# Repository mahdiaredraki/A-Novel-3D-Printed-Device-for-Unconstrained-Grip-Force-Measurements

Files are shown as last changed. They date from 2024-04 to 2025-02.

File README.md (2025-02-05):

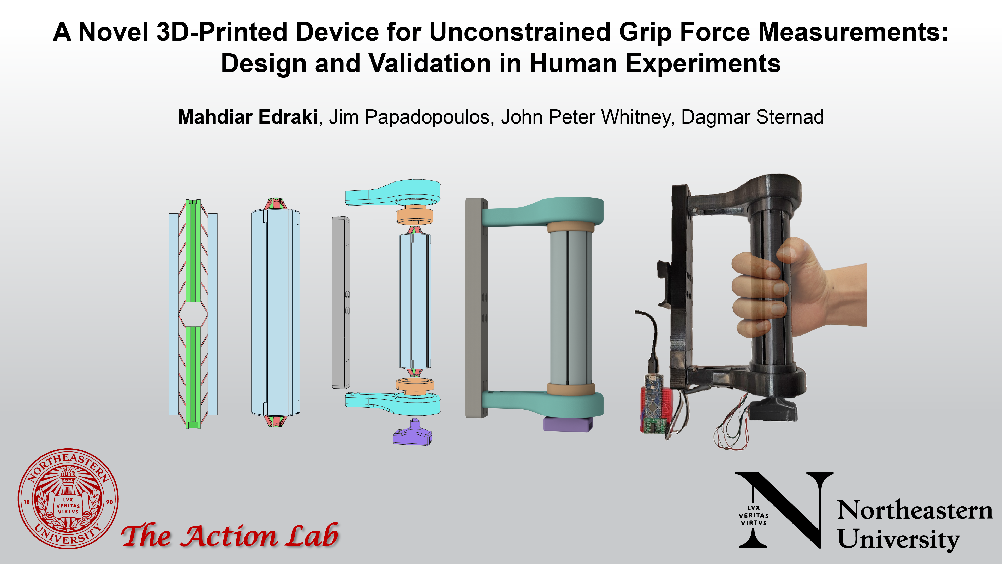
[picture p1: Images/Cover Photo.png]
Cover Photo


This repository contains the source code for the paper "A Novel 3D-Printed Device for Unconstrained Grip Force Measurements: Design and Application in a Human Experiment". This paper has been submitted to IEEE Transactions on Haptics.

## Setup Tutorial
[Click here](https://youtu.be/9uq_tFdBbcg?si=LtT3Q0BiFbUa_C0i) to view a step-by-step tutorial covering how to assemble and calibrate the device.

## Software
### Calibration and Programming of Arduino
The code to calibrate and program the arduino are provided in the [Grip Sensor Code/Arduino](https://github.com/mahdiaredraki/A-Novel-3D-Printed-Device-for-Unconstrained-Grip-Force-Measurements/tree/main/Grip%20Sensor%20Code/Arduino) folder. 

A README file is provided in the folder, explaining the steps to calibrate and program the device.

### Data Collection through MATLAB and C++
The code to record device data using MATLAB and C++ are provided in the [Grip Sensor Code/MATLAB](https://github.com/mahdiaredraki/A-Novel-3D-Printed-Device-for-Unconstrained-Grip-Force-Measurements/tree/main/Grip%20Sensor%20Code/MATLAB) and [Grip Sensor Code/C++](https://github.com/mahdiaredraki/A-Novel-3D-Printed-Device-for-Unconstrained-Grip-Force-Measurements/tree/main/Grip%20Sensor%20Code/C%2B%2B) folders, respectively.

## Hardware
* [Arduino Nano](https://a.co/d/btdwUGS)
* [HX711 Amplifier](https://a.co/d/b6gcvBy)
* [M3 Threaded Rod](https://a.co/d/1BYGkEt)
* [Jumper Wires](https://a.co/d/3KskUcE)
* [M3 Nuts](https://a.co/d/6aupH7b)
* [50kg Load Cell](https://www.aliexpress.us/item/3256803506004709.html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)
* [PLA Filament for 3D Printed Parts](https://a.co/d/9uJcKfV) 

## Assembly and Calibration Tools
* Soldering Iron
* Pliers x2
* Kitchen Scale or any calibrated Load Cell
* Weights

## Wiring Diagram
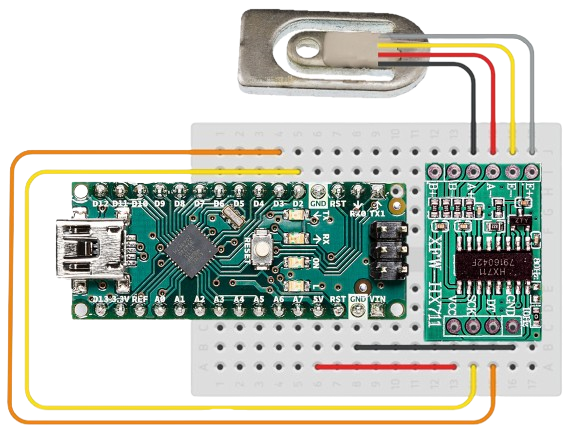
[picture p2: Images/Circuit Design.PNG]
Circuit Design


## 3D-Printed Parts
All CAD files developed in this project are open-sourced and can be found in the [CAD Files](https://github.com/mahdiaredraki/A-Novel-3D-Printed-Device-for-Unconstrained-Grip-Force-Measurements/tree/main/CAD%20Files) folder. All parts have been provided with .SLDPRT, .STL, and .STEP formats.

## Experiment Data
All the data collected and analyzed in this work are made available in the [Experiment Data](https://github.com/mahdiaredraki/A-Novel-3D-Printed-Device-for-Unconstrained-Grip-Force-Measurements/tree/main/Experiment%20Data) folder. The raw and cleaned up data of all seven participants can be found in the [Experiment Data/Participant Datasets](https://github.com/mahdiaredraki/A-Novel-3D-Printed-Device-for-Unconstrained-Grip-Force-Measurements/tree/main/Experiment%20Data/Participant%20Datasets) folder. The data used in the Analysis of Variance (ANOVA) in the study are also provided separately in the [Experiment Data/ANOVA Datasets](https://github.com/mahdiaredraki/A-Novel-3D-Printed-Device-for-Unconstrained-Grip-Force-Measurements/tree/main/Experiment%20Data/ANOVA%20Datasets) folder. 

## Contact Me
If you have any questions or have trouble setting up the device, feel free to reach out to Mahdi Edraki (edraki.m@northeastern.edu).

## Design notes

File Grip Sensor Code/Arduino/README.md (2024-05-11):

## Calibration
1. Open the Calibrate.ino code in Arduino IDE.
2. Upload the program onto the Arduino.
3. Open the Serial Monitor by clicking Tools -> Serial Monitor.
4. Apply a known load to the device.
5. Adjust the device output in the Serial Monitor by entering + or – until the reading matches the applied load.
6. Apply other loads and adjust the reading until a suitable calibration factor is obtained.
7. Note the calibration factor to be used in the Programming step below.

## Programming
1. Open the Program.ino code in Arduino IDE.
2. Modify the value for the calibration_factor variable to the value found in step 7 above.
3. Upload the program onto the Arduino.

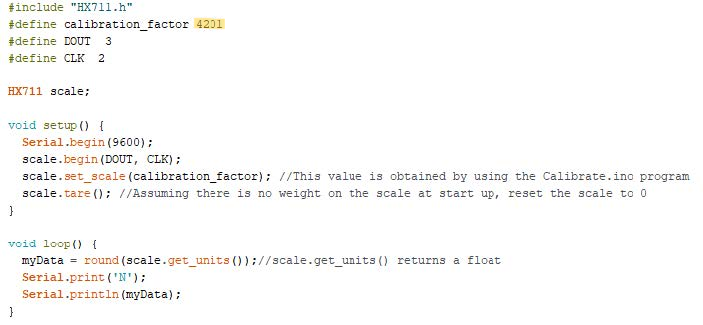
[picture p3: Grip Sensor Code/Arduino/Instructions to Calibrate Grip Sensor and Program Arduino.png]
Calibrate and Program


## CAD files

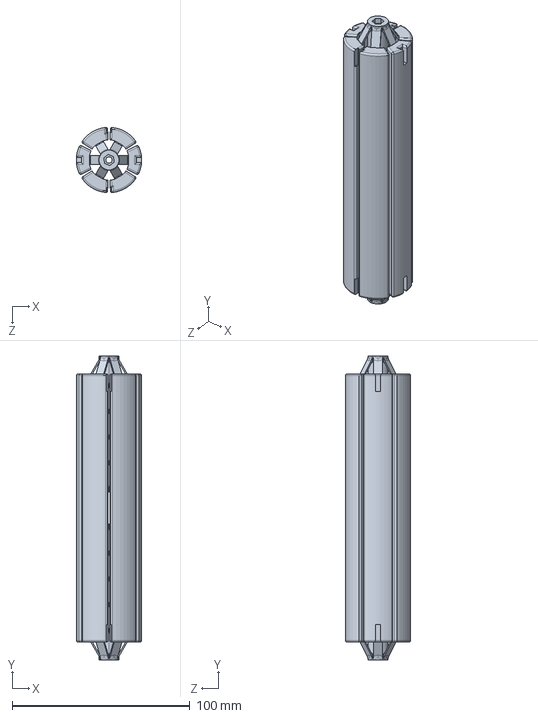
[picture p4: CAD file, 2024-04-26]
CAD Files/Grip Sensor Main Body.STEP
36.8 x 171.0 x 36.6 mm

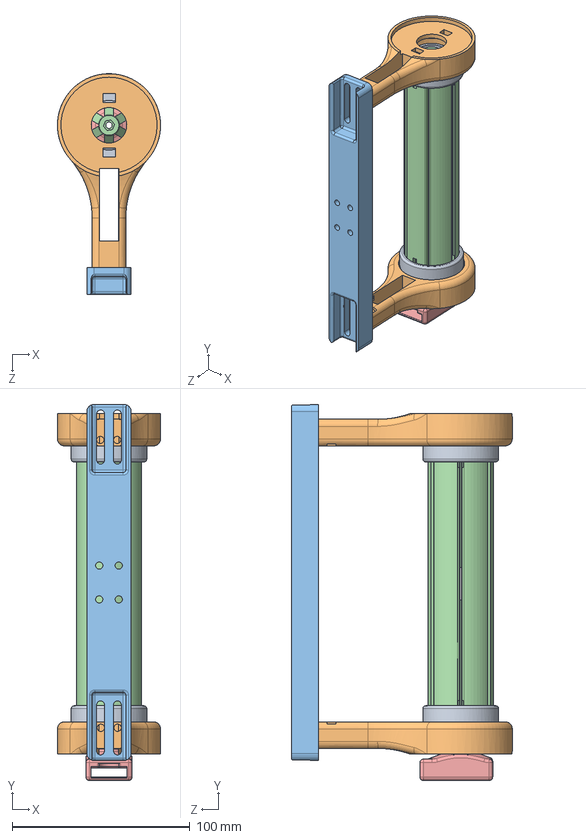
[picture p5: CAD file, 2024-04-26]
CAD Files/Complete Assembly.SLDASM
58.0 x 211.3 x 124.0 mm
Bearing Mount x 2
Handle Mount x 2
Handle Vertical Arm
Grip Sensor Main Body
Load Cell Mount

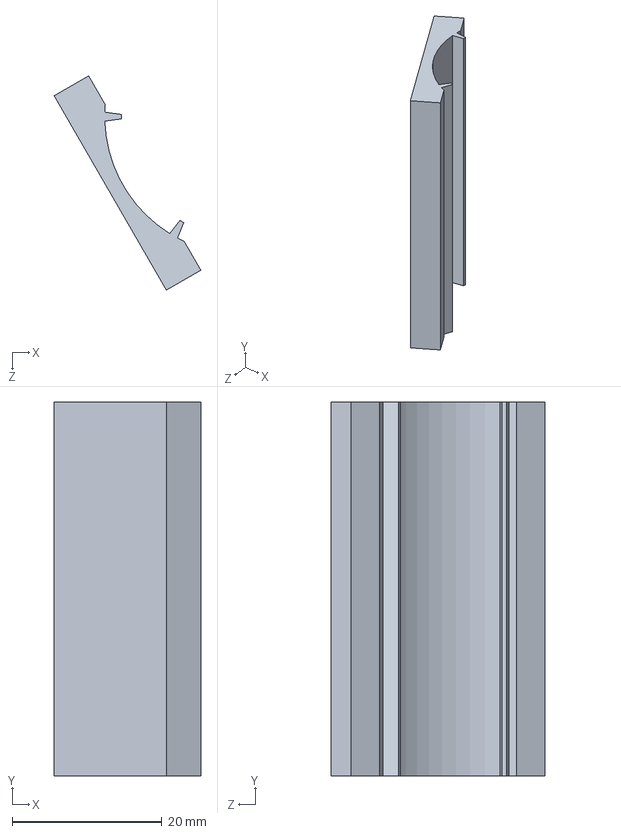
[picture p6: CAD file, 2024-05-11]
CAD Files/Load Application Plate.STEP
19.6 x 50.0 x 28.6 mm

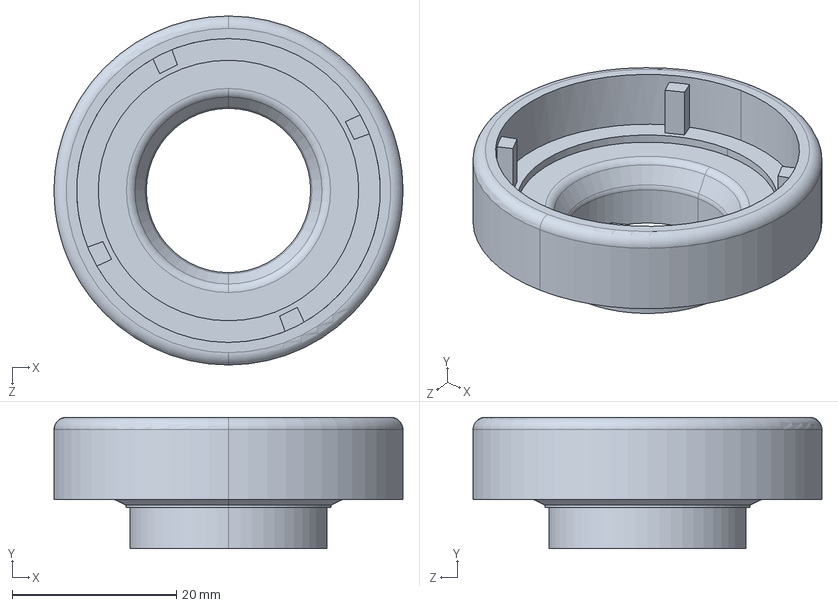
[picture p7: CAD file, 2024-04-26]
CAD Files/Bearing Mount.STEP
42.5 x 16.0 x 42.5 mm

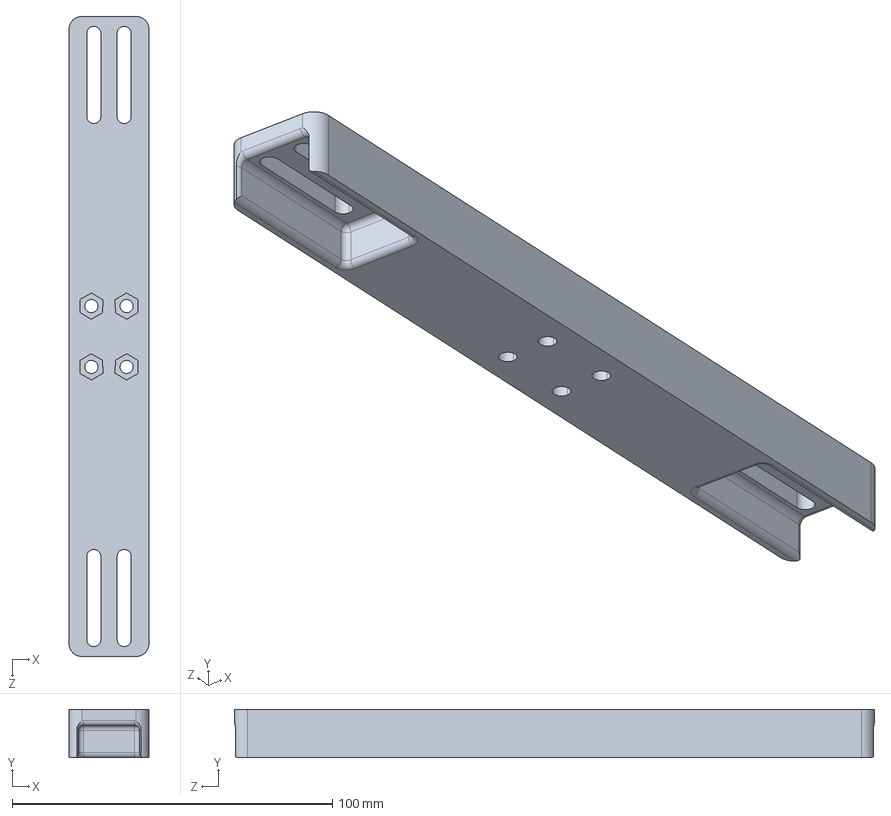
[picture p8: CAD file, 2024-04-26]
CAD Files/Handle Vertical Arm.STEP
25.0 x 15.0 x 200.0 mm

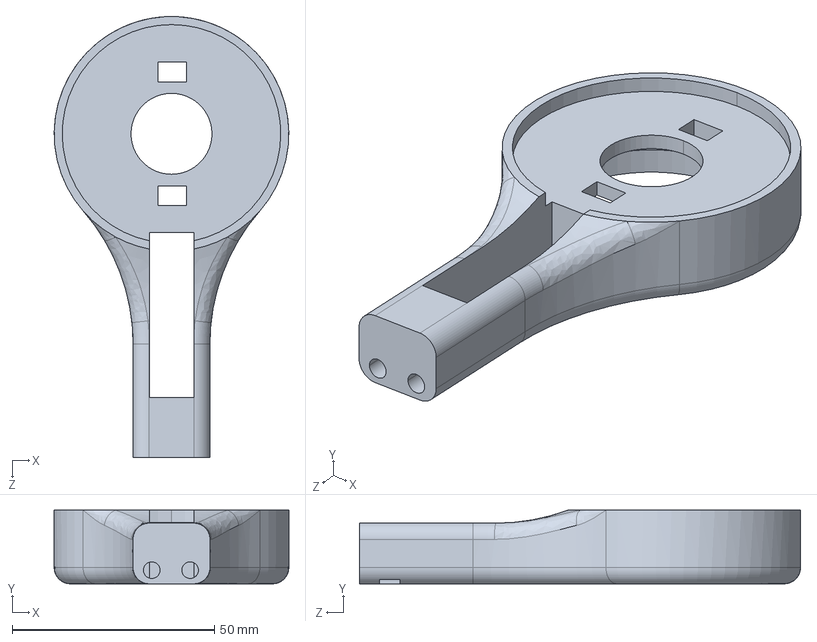
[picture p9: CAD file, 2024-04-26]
CAD Files/Handle Mount.STEP
58.0 x 18.2 x 109.0 mm

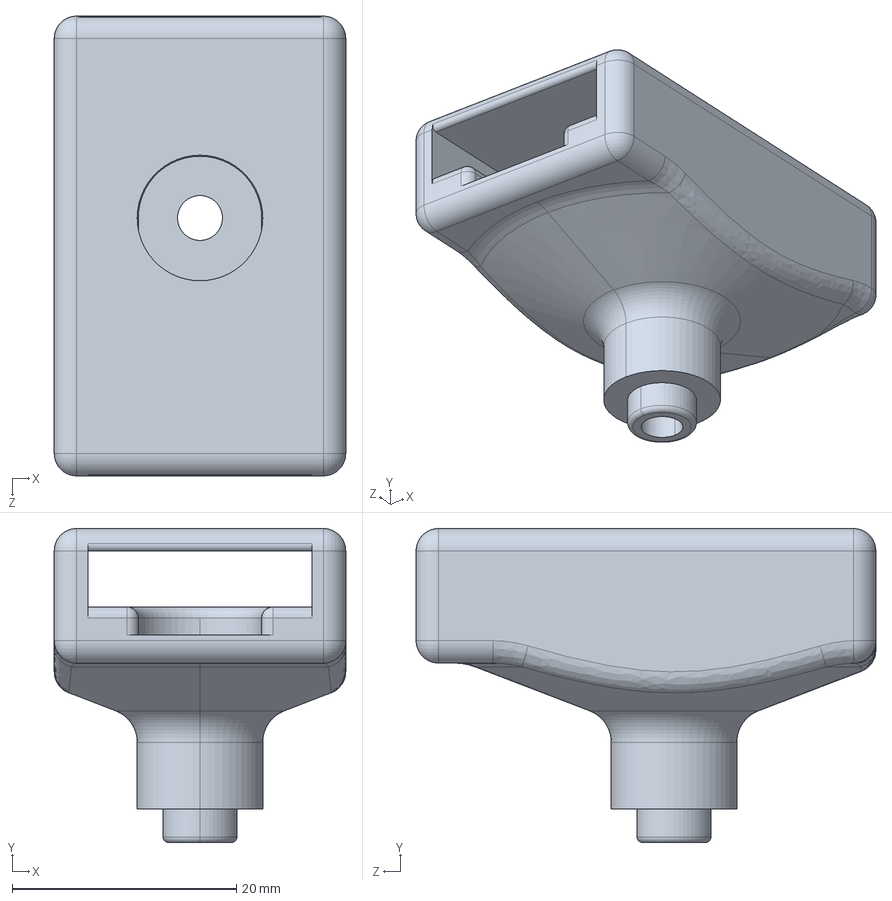
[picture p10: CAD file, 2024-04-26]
CAD Files/Load Cell Mount.STEP
26.0 x 28.0 x 41.0 mm

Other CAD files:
CAD Files/Bearing Mount.SLDPRT
CAD Files/Bearing Mount.STL
CAD Files/Grip Sensor Main Body.SLDPRT
CAD Files/Grip Sensor Main Body.STL
CAD Files/Handle Mount.SLDPRT
CAD Files/Handle Mount.STL
CAD Files/Handle Vertical Arm.SLDPRT
CAD Files/Handle Vertical Arm.STL
CAD Files/Load Application Plate.SLDPRT
CAD Files/Load Application Plate.STL
CAD Files/Load Cell Mount.SLDPRT
CAD Files/Load Cell Mount.STL

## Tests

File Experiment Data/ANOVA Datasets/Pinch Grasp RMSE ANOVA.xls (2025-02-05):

Subject | Difficulty Level | Task | RMSE
1 | 1 | Force Only | 0.1138611885
1 | 1 | Force Only | 0.1383625345
1 | 1 | Force Only | 0.1025290186
1 | 1 | Force Only | 0.1250493093
1 | 1 | Force Only | 0.114308554
1 | 2 | Force Only | 0.2012469775
1 | 2 | Force Only | 0.3908800715
1 | 2 | Force Only | 0.3616852296
1 | 2 | Force Only | 0.3871173755
1 | 2 | Force Only | 0.3948475701
1 | 3 | Force Only | 0.9486531392
1 | 3 | Force Only | 0.7340562798
1 | 3 | Force Only | 0.8497083643
1 | 3 | Force Only | 0.786455041
1 | 3 | Force Only | 0.7600434911
2 | 1 | Force Only | 0.0191234433
2 | 1 | Force Only | 0.02552317761
2 | 1 | Force Only | 0.03390090398
2 | 1 | Force Only | 0.05521848827
2 | 1 | Force Only | 0.07296641976
2 | 2 | Force Only | 0.2807133813
2 | 2 | Force Only | 0.3825199637
2 | 2 | Force Only | 0.3418847986
2 | 2 | Force Only | 0.3091413599
2 | 2 | Force Only | 0.2913149833
2 | 3 | Force Only | 1.054633165
2 | 3 | Force Only | 0.9352986354
2 | 3 | Force Only | 0.8806822812
2 | 3 | Force Only | 0.8580908812
2 | 3 | Force Only | 0.8305508158
3 | 1 | Force Only | 0.3140416317
3 | 1 | Force Only | 0.2239192144
3 | 1 | Force Only | 0.2237500758
3 | 1 | Force Only | 0.2446339993
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

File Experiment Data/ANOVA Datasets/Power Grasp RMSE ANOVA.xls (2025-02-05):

Subject | Difficulty Level | Task | RMSE
1 | 1 | Force Only | 1.543053112
1 | 1 | Force Only | 1.081428705
1 | 1 | Force Only | 1.24512971
1 | 1 | Force Only | 1.260448052
1 | 1 | Force Only | 1.285786486
1 | 2 | Force Only | 2.249098693
1 | 2 | Force Only | 1.577973864
1 | 2 | Force Only | 1.9240212
1 | 2 | Force Only | 1.685886376
1 | 2 | Force Only | 1.579800544
1 | 3 | Force Only | 3.726168373
1 | 3 | Force Only | 4.773870951
1 | 3 | Force Only | 4.378111724
1 | 3 | Force Only | 3.890191342
1 | 3 | Force Only | 3.52134578
2 | 1 | Force Only | 0.7863524557
2 | 1 | Force Only | 0.9991496171
2 | 1 | Force Only | 0.9049207744
2 | 1 | Force Only | 0.8263057425
2 | 1 | Force Only | 0.7686576595
2 | 2 | Force Only | 2.114027639
2 | 2 | Force Only | 1.939738249
2 | 2 | Force Only | 1.906579895
2 | 2 | Force Only | 1.788130997
2 | 2 | Force Only | 1.869472874
2 | 3 | Force Only | 3.984621104
2 | 3 | Force Only | 4.127334203
2 | 3 | Force Only | 3.609757387
2 | 3 | Force Only | 3.509388739
2 | 3 | Force Only | 3.323836977
3 | 1 | Force Only | 3.559765462
3 | 1 | Force Only | 2.968248639
3 | 1 | Force Only | 2.771469925
3 | 1 | Force Only | 2.224066566
3 | 1 | Force Only | 2.208725277
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

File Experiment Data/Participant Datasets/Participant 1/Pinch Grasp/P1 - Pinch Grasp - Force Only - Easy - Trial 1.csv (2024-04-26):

Time | X_Position | Y_Position | Grip_Force | Vertical_Error | Grip_Force_Error
0 | 0.11 | 0.01098711 | 7.44158 | 0 | 0
0.0118999999999989 | 0.10925 | 0.011093175 | 7.46515 | 0 | 0
0.0238999999999994 | 0.1085 | 0.011193885 | 7.48753 | 0 | 0
0.0358999999999998 | 0.10775 | 0.01133352 | 7.51856 | 0 | 0
0.0478999999999985 | 0.107 | 0.01146618 | 7.54804 | 0 | 0
0.059899999999999 | 0.10625 | 0.011592225 | 7.57605 | 0 | 0
0.0718999999999994 | 0.1055 | 0.011779515 | 7.61767 | 0 | 0
0.0838999999999999 | 0.10475 | 0.011957445 | 7.65721 | 0 | 0
0.0958999999999985 | 0.104 | 0.01228536 | 7.73008 | 0 | 0
0.107899999999999 | 0.10325 | 0.012596895 | 7.79931 | 0 | 0
0.119899999999999 | 0.1025 | 0.01289286 | 7.86508 | 0 | 0
0.1319 | 0.10175 | 0.013346325 | 7.96585 | 0 | 0
0.143899999999999 | 0.101 | 0.01377711 | 8.06158 | 0 | 0
0.155899999999999 | 0.10025 | 0.014186385 | 8.15253 | 0 | 0
0.167999999999999 | 0.0995 | 0.01475838 | 8.27964 | 0 | 0
0.180099999999999 | 0.09875 | 0.0153018 | 8.4004 | 0 | 0
0.192 | 0.098 | 0.01585548 | 8.52344 | 0 | 0
0.203899999999999 | 0.09725 | 0.01638144 | 8.64032 | 0 | 0
0.2159 | 0.0965 | 0.01688112 | 8.75136 | 0 | 0
0.2279 | 0.09575 | 0.017700885 | 8.93353 | 0 | 0
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

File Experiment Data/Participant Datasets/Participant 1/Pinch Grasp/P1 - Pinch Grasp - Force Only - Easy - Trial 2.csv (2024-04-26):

Time | X_Position | Y_Position | Grip_Force | Vertical_Error | Grip_Force_Error
0 | 0.11 | 0.008845605 | 6.96569 | 0 | 0
0.0118999999999998 | 0.10925 | 0.008871435 | 6.97143 | 0 | 0
0.0238700000000005 | 0.1085 | 0.00889596 | 6.97688 | 0 | 0
0.0360300000000002 | 0.10775 | 0.00891927 | 6.98206 | 0 | 0
0.0478899999999998 | 0.107 | 0.00902745 | 7.0061 | 0 | 0
0.0599600000000002 | 0.10625 | 0.00913023 | 7.02894 | 0 | 0
0.0718899999999998 | 0.1055 | 0.00943191 | 7.09598 | 0 | 0
0.0838900000000002 | 0.10475 | 0.00971847 | 7.15966 | 0 | 0
0.0958899999999998 | 0.104 | 0.00999072 | 7.22016 | 0 | 0
0.10792 | 0.10325 | 0.010376865 | 7.30597 | 0 | 0
0.119870000000001 | 0.1025 | 0.010743705 | 7.38749 | 0 | 0
0.13187 | 0.10175 | 0.01119969 | 7.48882 | 0 | 0
0.14386 | 0.101 | 0.011632815 | 7.58507 | 0 | 0
0.15589 | 0.10025 | 0.01204434 | 7.67652 | 0 | 0
0.16809 | 0.0995 | 0.01260072 | 7.80016 | 0 | 0
0.179860000000001 | 0.09875 | 0.01312929 | 7.91762 | 0 | 0
0.19189 | 0.098 | 0.014037885 | 8.11953 | 0 | 0
0.20388 | 0.09725 | 0.01490103 | 8.31134 | 0 | 0
0.21589 | 0.0965 | 0.015721065 | 8.49357 | 0 | 0
0.22787 | 0.09575 | 0.01678761 | 8.73058 | 0 | 0
0.23988 | 0.095 | 0.017800875 | 8.95575 | 0 | 0
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

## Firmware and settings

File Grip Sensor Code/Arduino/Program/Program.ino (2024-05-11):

#include "HX711.h"
#define calibration_factor 4201
#define DOUT  3
#define CLK  2

HX711 scale;
float myData = 0.0;

void setup() {
  Serial.begin(9600);
  scale.begin(DOUT, CLK);
  scale.set_scale(calibration_factor); //This value is obtained by using the Calibrate.ino program
  scale.tare(); //Assuming there is no weight on the scale at start up, reset the scale to 0
}

void loop() {
  myData = scale.get_units();//scale.get_units() returns a float
  Serial.print('N');
  Serial.println(myData); 
}

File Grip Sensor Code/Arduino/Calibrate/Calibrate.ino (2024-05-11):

/*
 Example using the SparkFun HX711 breakout board with a scale
 By: Nathan Seidle
 SparkFun Electronics
 Date: November 19th, 2014
 License: This code is public domain but you buy me a beer if you use this and we meet someday (Beerware license).

 This is the calibration sketch. Use it to determine the calibration_factor that the main example uses. It also
 outputs the zero_factor useful for projects that have a permanent mass on the scale in between power cycles.

 Setup your scale and start the sketch WITHOUT a weight on the scale
 Once readings are displayed place the weight on the scale
 Press +/- or a/z to adjust the calibration_factor until the output readings match the known weight
 Use this calibration_factor on the example sketch

 This example assumes pounds (lbs). If you prefer kilograms, change the Serial.print(" lbs"); line to kg. The
 calibration factor will be significantly different but it will be linearly related to lbs (1 lbs = 0.453592 kg).

 Your calibration factor may be very positive or very negative. It all depends on the setup of your scale system
 and the direction the sensors deflect from zero state
 This example code uses bogde's excellent library: https://github.com/bogde/HX711
 bogde's library is released under a GNU GENERAL PUBLIC LICENSE
 Arduino pin 2 -> HX711 CLK
 3 -> DOUT
 5V -> VCC
 GND -> GND

 Most any pin on the Arduino Uno will be compatible with DOUT/CLK.

 The HX711 board can be powered from 2.7V to 5V so the Arduino 5V power should be fine.

*/

#include "HX711.h"

#define DOUT  3
#define CLK  2

HX711 scale;

float calibration_factor = -7050; //-7050 worked for my 440lb max scale setup

void setup() {
  Serial.begin(9600);
  Serial.println("HX711 calibration sketch");
  Serial.println("Remove all weight from scale");
  Serial.println("After readings begin, place known weight on scale");
  Serial.println("Press + or a to increase calibration factor");
  Serial.println("Press - or z to decrease calibration factor");

  scale.begin(DOUT, CLK);
  scale.set_scale();
  scale.tare(); //Reset the scale to 0

  long zero_factor = scale.read_average(); //Get a baseline reading
  Serial.print("Zero factor: "); //This can be used to remove the need to tare the scale. Useful in permanent scale projects.
  Serial.println(zero_factor);
}

void loop() {

  scale.set_scale(calibration_factor); //Adjust to this calibration factor

  Serial.print("Reading: ");
  Serial.print(scale.get_units(), 1);
  Serial.print(" lbs"); //Change this to kg and re-adjust the calibration factor if you follow SI units like a sane person
  Serial.print(" calibration_factor: ");
  Serial.print(calibration_factor);
  Serial.println();

  if(Serial.available())
  {
    char temp = Serial.read();
    if(temp == '+' || temp == 'a')
      calibration_factor += 0.1;
    else if(temp == '-' || temp == 'z')
      calibration_factor -= 0.1;
  }
}

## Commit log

2024-05-11 Upload Load Application Plate File
    [Load Application Plate.SLDPRT, Load Application Plate.STEP, Load Application Plate.STL]
2024-05-12 changed grip sensor output from int to double
2025-02-05 Update README and Participant Data
    [P1 - Pinch Grasp - Force with Displacement - Easy - Trial 1.csv, P1 - Pinch Grasp - Force with Displacement - Easy - Trial 2.csv, P1 - Pinch Grasp - Force with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]
